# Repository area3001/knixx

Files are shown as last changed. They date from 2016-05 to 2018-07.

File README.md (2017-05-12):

## knixx

Knixx houses all our research and trials into opensource KNX compatible modules.

### knixx SW4

Our first development board is a 4 or 6 button KNX compatible switch which fits in an [Niko](http://niko.eu) (system 45) housing. This form factor is very common in Belgium whilst other parts of Europe use system 55. The board is designed around the ON Semiconductor [NCN5121 KNX Transceiver](http://www.onsemi.com/PowerSolutions/product.do?id=NCN5121) and a STMicroelectronics [STM32F070C6T6 Cortex-M0 Microcontroller](http://www.st.com/content/st_com/en/products/microcontrollers/stm32-32-bit-arm-cortex-mcus/stm32f0-series/stm32f0x0-value-line/stm32f070c6.html). The 4 switch variant provides options to add a Sensirion [SHT20 humidity sensor](https://www.sensirion.com/fileadmin/user_upload/customers/sensirion/Dokumente/Humidity_Sensors/Sensirion_Humidity_Sensors_SHT20_Datasheet_V4.pdf) a Panasonic [EKMC1601113 motion sensor](https://duckduckgo.com/?q=EKMC1601113) and a miniature AMS [TSL2584TSV ambient light sensor](http://ams.com/eng/Products/Light-Sensors/Ambient-Light-Sensors/TSL2584TSV). The board features a Micro USB connector on the back for configuration purposes. 

#### Top 3D render of the 4 switch variant with sensors

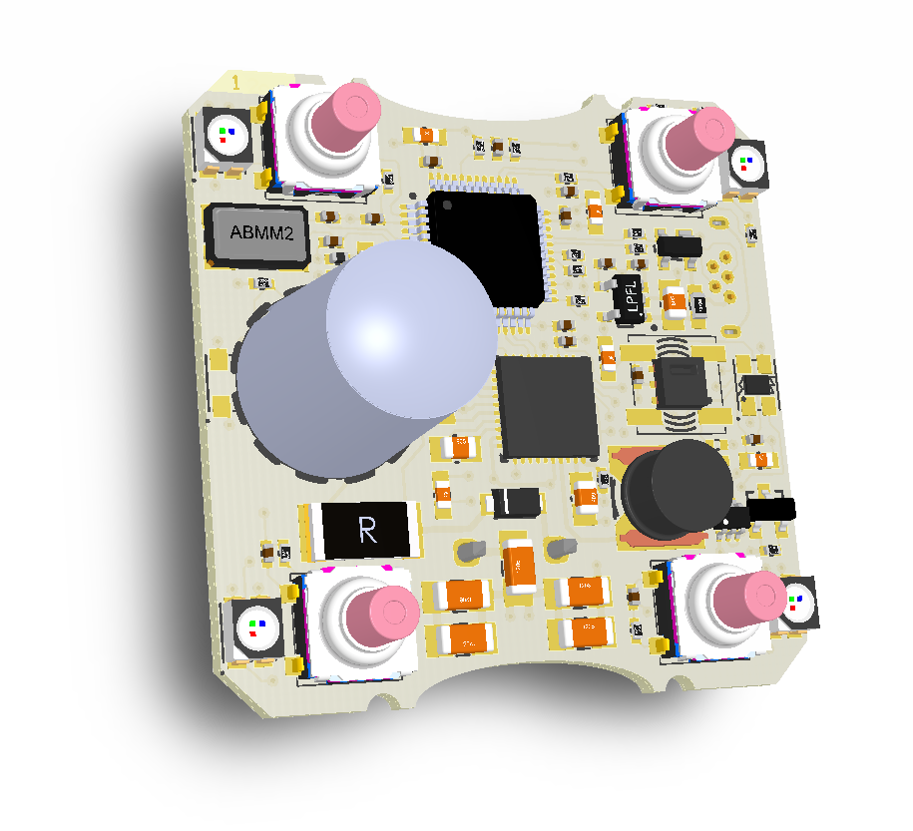
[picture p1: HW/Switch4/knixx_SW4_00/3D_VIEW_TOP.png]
knixx_SW4_00_top 4SW version


#### Top 3D render of the 6 switch variant

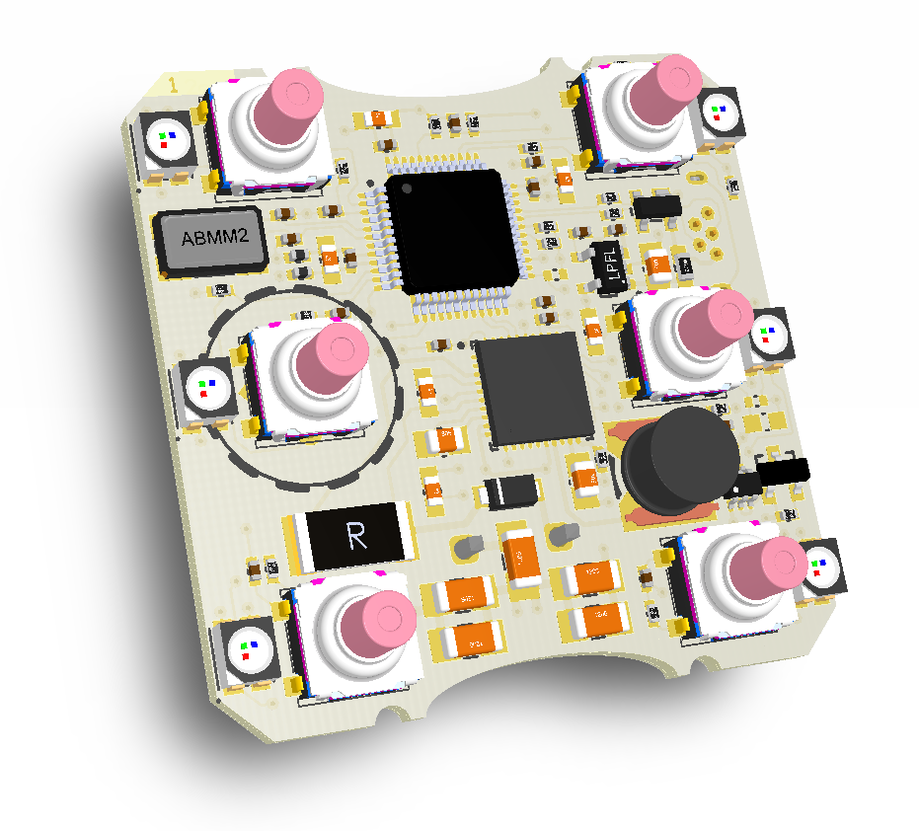
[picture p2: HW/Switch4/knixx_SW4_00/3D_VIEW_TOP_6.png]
knixx_SW4_00_top 6SW version


#### Bottom 3D render

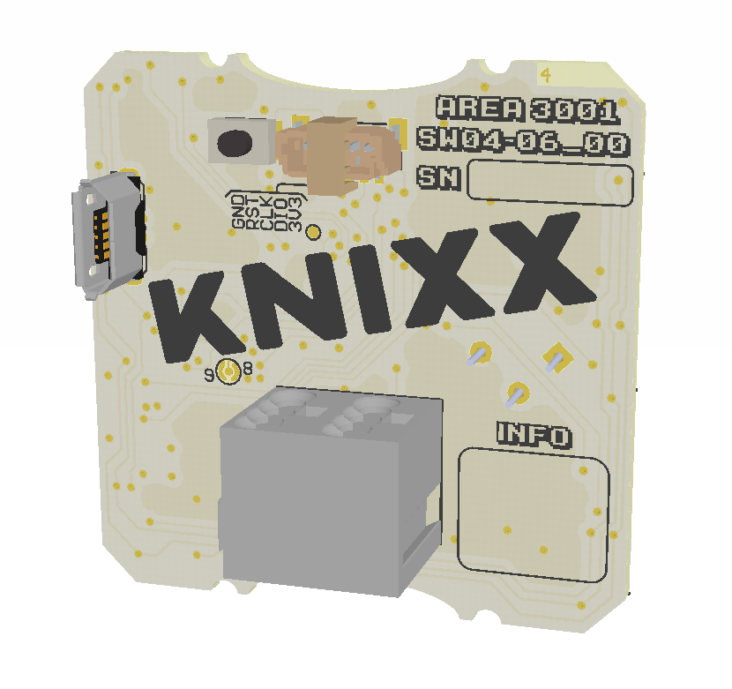
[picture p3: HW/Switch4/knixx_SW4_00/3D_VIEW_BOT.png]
knixx_SW4_00_bot


### knixx Fez

The knixx Fez features the same [NCN5121 KNX Transceiver](http://www.onsemi.com/PowerSolutions/product.do?id=NCN5121) as our switch but interfaces this with the Raspberry Pi. The board als has a [Ti BQ32000](http://www.ti.com/product/BQ32000) RTC, two EEPROMs and a general purpose LED and button.

#### 3D render

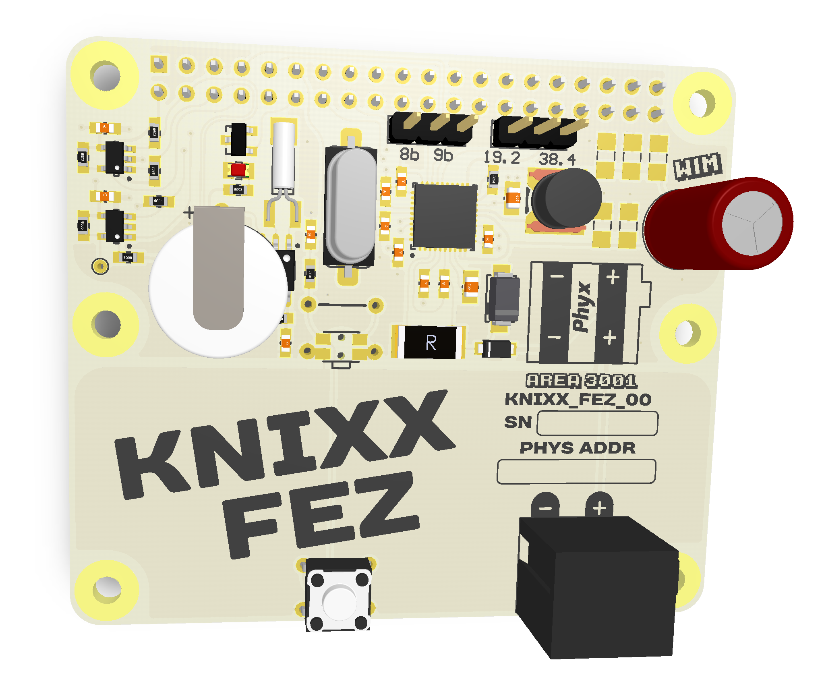
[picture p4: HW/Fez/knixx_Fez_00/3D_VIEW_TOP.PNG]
knixx_Fez_00_top

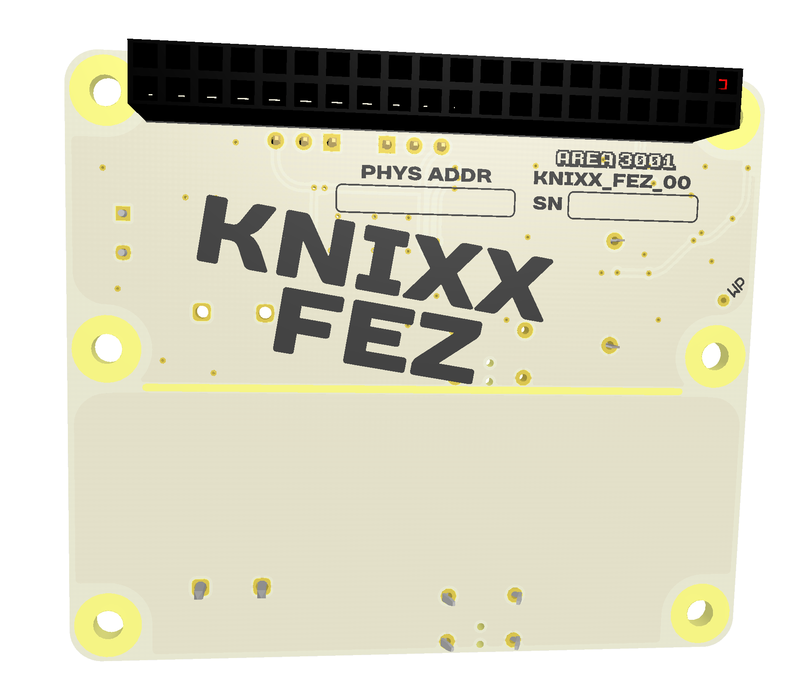
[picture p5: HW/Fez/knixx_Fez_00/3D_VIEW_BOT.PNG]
knixx_Fez_00_bot


### knixx ???

What's next? A system 55 version? Actuators? BeagleBoard Cape?

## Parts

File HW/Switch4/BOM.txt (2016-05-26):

PN; Description; Brand; Supplier1; Supplier1 Price; Supplier1 PN; Supplier2; Supplier2 Price; Supplier2 PN
NCN5121; KNX Transceiver; ON Semi
CLV1A-FKB; RGB PLC4 LED; Cree
TL3301CF260QJ; Tactswitch SMD; E-Switch
KSC621JLFS; Tactswitch SMD 1.6Newton;SMK Components; Farnell; 0,46; 2320054RL; Digikey; 0,387; 401-1748-2-ND
KSC641JLFS; Tactswitch SMD 3Newton; SMK Components; Farnell; ; 2320056RL; Digikey; 0,387; 404-1788-1-ND
11AA010T-I/TT; EEPROM 1Kx8; Microchip; Farnell; 0.148; 157828RL; Digikey; 0,143; 
STM32F030C6T6; uC Cortex-M0, 48 MHz, 32 KB flash, 4 KB RAM, LQFP48; ST Micro
STM32F070C6T6; uC Cortex-M0, 48 MHz, 32 KB flash, 4 KB RAM, LQFP48, USB; ST Micro
243-131; KNX pins; Wago
243-211; KNX connector Red/Black; Wago
SHT20; Digital Humidity Sensor; Sensirion; 
VCNL4010; Fully Integrated Proximity and Ambient Light Sensor with Infrared; Vishay
EKMC1601111; PIR; Panasonic
614105150721; USB conn, Würth or similar straight TH micro USB B connector
Elec. Mic.

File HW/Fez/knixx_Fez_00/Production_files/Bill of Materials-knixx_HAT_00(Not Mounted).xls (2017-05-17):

Bill of Materials |  |  | knixx_HAT
Project: |  | knixx_HAT_00.PrjPcb
Revision: |  | 00
Variant: |  | Not Mounted
Creation Date: | 12/05/2017 | 16:02:06
Print Date: | 2017-05-17 | 11:41:44
Footprint | Comment | LibRef | Designator | Value | Description | Supplier 1 | Supplier Part Number 1 | Quantity
BR-1220_HFN | BR-1220/HFN 35mAh | BAT BR-1220/HFN | BAT1 | 1220 |  | Farnell | 1892653 (https://octopart-clicks.com/click/altium?manufacturer=PANASONIC%20ELECTRONIC%20COMPONENTS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) | 1
C0603_N | CAP_CERAMIC | CAP # 100nF 16V 0603 | C1, C15, C17, C19 | 100nF 16V | Capacitor Ceramic |  |  | 4
C0603_N | CAP_CERAMIC | CAP # 10nF 16V 0603 | C2, C3, C18 | 10nF 16V | Capacitor Ceramic |  |  | 3
C0805_N | CAP_CERAMIC | CAP # 220nF 50V 0805 | C4 | 220nF 50V | Capacitor Ceramic | Farnell | 2496964 (https://octopart-clicks.com/click/altium?sku=2496964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) | 1
C0603_N | CAP_CERAMIC | CAP # 100nF 50V 0603 | C5 | 100nF 50V | Capacitor Ceramic | Farnell | 1759122 (https://octopart-clicks.com/click/altium?sku=1759122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) | 1
C0603_N | CAP_CERAMIC | CAP # 47nF 50V 0603 | C6 | 47nF 50V | Capacitor Ceramic | Farnell | 2496867 (https://octopart-clicks.com/click/altium?sku=2496867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) | 1
C0805_N | CAP_CERAMIC | CAP # 10uF 10V 0805 | C7 | 10uF 10V | Capacitor Ceramic | Farnell | 2320859 (https://octopart-clicks.com/click/altium?sku=2320859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) | 1
C0603_N | CAP_CERAMIC | CAP # 12pF 50V 0402 | C8, C9 | 12pF | Capacitor Ceramic | Farnell | 1759054 (https://octopart-clicks.com/click/altium?sku=1759054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) | 2
C_8x11.5_3.5mm | CAP_POL | CAP 100uF 50V 8x11mm | C16 | 100uF 50V | Capacitor electrolyt | Farnell | 9693793 (https://octopart-clicks.com/click/altium?manufacturer=PANASONIC%20ELECTRONIC%20COMPONENTS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) | 1
WAGO_243-211 | CONNECTOR FOR EIB APPLICATIONS PUSH-WIRE® CONNECTION | Wago 243-211 Connector EIB | CON2 | 243-211 |  | Farnell | 4016014 | 1
ON_SOD-123FL | NTS260SFT1G Schottky Rectifier, Single, 60 V, 2 A, SOD-123, 650 mV | Schottky # NTS260SFT1G | D1 | NTS260SFT1G |  | Farnell | 2473419 (https://octopart-clicks.com/click/altium?sku=2473419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) | 1
LED_0805_RD | Default 0805 Red LED | LED # Red 0805 | D2 |  |  | Farnell | 2099236 (https://octopart-clicks.com/click/altium?sku=2099236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) | 1
SMA_AC | TVS Diode 40V 400W Unidirectional DO-214AC | TVS # UNI 40V 1SMA40AT3G | D3 | 1SMA40AT3G |  | Farnell | 2533119 (https://octopart-clicks.com/click/altium?sku=2533119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) | 1
IND_6045 | 220µH INDUCTOR | IND # 220uH 6.0x6.0mm SRN6045TA-221M | L1 | 220µH IND |  | Farnell | 2616905 (https://octopart-clicks.com/click/altium?sku=2616905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) | 1
HDR1X3 | Header 3 | Pin Header 2.54mm 3way | P3, P4 |  |  |  |  | 2
WAGO_243-131 | SOLDER PIN FOR PCBS UP TO 2 MM | Wago 234-131 Solder pin | P5, P6 | 243-131 |  | Farnell | 2643506 | 2
RCPT2X20 | Header 20X2 | Receptable 2.54mm dual row 40way | Pi |  |  |  |  | 1
R0603_N | RESISTOR | RES # 1K 0603 | R1, R2, R3, R5, R6, R8, R11 | 1K |  |  |  | 7
R2512 | RESISTOR | RES # 27R 2512 | R4 | 27R |  | Farnell | 1265189 | 1
R0603_N | RESISTOR | RES # 1R 0402 | R7 | 1R |  |  |  | 1
R0603_N | RESISTOR | RES # 270R 0603 | R9 | 270R |  | Farnell | 2497841 (https://octopart-clicks.com/click/altium?sku=2497841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) | 1
R0603_N | RESISTOR | RES # 100R 0603 | R10 | 100R |  |  |  | 1
TACTSW | Default TH TACT | SW TACT | SW4 |  |  |  |  | 1
SOT23-3 | 0.2A N-Ch MOSFET Vgs 3.2 | BSS138 N-Ch MOSFET 0.2A 3.2Vgs 60Vds | T1 | BSS138 |  | Farnell | 2432717 (https://octopart-clicks.com/click/altium?sku=2432717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) | 1
TP_1.2mm_0.6mm | TEST_PAD | TP 1.2mm | TP4 | NO BOM |  |  |  | 1
SOT23-5 | Serial EEPROM 64K (8b) SOT35 I2C | EEPROM # I2C 8Kx8b 24LC64T-I/OT | U1, U3 | 24LC64T-I/OT |  | Farnell | 1700992 (https://octopart-clicks.com/click/altium?sku=1700992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) | 2
ONS_QFN40_6x6 | KNX Transceiver for Twisted Pair Networks | KNX # NCN5121 | U2 | NCN5121 |  | DigiKey | NCN5121MNTWGOSTR-ND | 1
SOIC_N_8 | I2C RTC Ti BQ32000 | RTC # BQ32000 | U4 | BQ32000DR |  | Farnell | 1754773 (https://octopart-clicks.com/click/altium?sku=1754773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) | 1
HC49US_SMD | 16MHz 20pF HC49S Fox | XTAL # 16Mhz HC49S | Y1 | 16MHz | Crystal Oscillator | Farnell | 2058001 (https://octopart-clicks.com/click/altium?sku=2058001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) | 1
CMR200T | 32.768Khz CMR200 12.5pF | XTAL # 32.768Khz 12.5pF CMR200 | Y2 | 32.768KHz | Crystal Oscillator | Farnell | 1100758 (https://octopart-clicks.com/click/altium?manufacturer=CITIZEN%20FINETECH%20MIYOTA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) | 1
 |  |  |  |  |  |  |  | 45
Approved |  | Notes

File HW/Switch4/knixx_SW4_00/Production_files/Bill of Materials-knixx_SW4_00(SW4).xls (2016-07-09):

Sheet: BOM Report
Bill of Materials |  |  | Variant [SW4] of [knixx_SW4_00]
Source Data From: |  | knixx_SW4_00.PrjPcb
Project: |  | knixx_SW4_00.PrjPcb
Variant: |  | SW4
Creation Date: | 4/07/2016 | 11:22:56
Print Date: | 42555 | 42555.49438
Footprint | Comment | LibRef | Designator | Value | Description | Supplier 1 | Supplier Part Number 1 | Quantity
C0402 |  | CAP # 100nF 16V 0402 | C1, C6, C7, C13 | 100nF 16V | Capacitor Ceramic | Farnell | 1758896 | 4
C0402 |  | CAP # 10nF 16V 0402 | C2, C8, C9, C10, C11, C12, C20, C21, C23, C25, C28 | 10nF 16V | Capacitor Ceramic | Farnell | 1758924 | 11
C0603_N |  | CAP # 1uF 16V 0603 | C3, C4, C26, C27, C34 | 1uF 16V | Capacitor Ceramic | Farnell | 2320814 | 5
C0805_N |  | CAP # 10uF 10V 0805 | C5, C19 | 10uF 10V | Capacitor Ceramic | Farnell | 2320859 | 2
C0402 |  | CAP # 12pF 50V 0402 | C14, C15 | 12pF | Capacitor Ceramic | Farnell | 2310489 | 2
C0805_N |  | CAP # 220nF 50V 0805 | C16 | 220nF 50V | Capacitor Ceramic | Farnell | 2496964 | 1
C0603_N |  | CAP # 100nF 50V 0603 | C17 | 100nF 50V | Capacitor Ceramic | Farnell | 1759122 | 1
C0603_N |  | CAP # 47nF 50V 0603 | C18 | 47nF 50V | Capacitor Ceramic | Farnell | 2496867 | 1
C1206_N |  | CAP # 22uF 35V 1206 X5R | C29, C30, C31, C32, C33 | 22uF 35V | Capacitor Ceramic | Digikey | 445-8045-1-ND | 5 | China Sourced
WAGO_243-211 | CONNECTOR FOR EIB APPLICATIONS PUSH-WIRE® CONNECTION | Wago 243-211 Connector EIB | CON1 | 243-211 |  |  |  | 1
Cree_CLV1A-FKB | PLCC2 general purpose RGB LED Cree CLV1A-FKB | LED # RGB PLCC2 CLV1A-FKB | D1, D2, D3, D4 | CLV1A-FKB | =Description |  |  | 4
SOT-143 | Low Capacitanse TVS Diode array | TVS # YSSR05 | D7 | YSSR05 | =Description | China |  | 1
ON_SOD-123FL | NTS260SFT1G Schottky Rectifier, Single, 60 V, 2 A, SOD-123, 650 mV | Schottky # NTS260SFT1G | D8 | NTS260SFT1G | =Description | Farnell | 2473419 | 1
L0402 | BLM15AX102SN1D | FER # 1K 0A35 0402 0R49 BLM15AX102SN1D | F1, F2 | 0A35 0R49 |  | Farnell | 2443221 | 2
WE_614105150721 | Vertical Micro USB B 614105150721 | USB Micro B TH VERTICAL 614105150721 | J1 | 614105150721 |  |  |  | 1
IND_6045 | SRU5028-100Y | IND # 10uH 5.2x5.2mm SRU5028-100Y | L1 | 10uH |  | Farnell | 1362078 | 1
WE_665305124022 | Header 1.0mm Shrouded 5 | HDR # SHR 1.0mm 5way - 665305124022 | P1 | 665305124022 |  |  |  | 1
WAGO_243-131 | SOLDER PIN FOR PCBS UP TO 2 MM | Wago 234-131 Solder pin | P2, P3 | 243-131 |  |  |  | 2
SOLDER_SW_C_1MM_3 | 3 pin Solder SW Circular 1mm | SW # Solder 3 pin Circular 1mm | P4 |  |  |  |  | 1
R0402 |  | RES # 100K 0402 | R1, R2 | 100K |  |  |  | 2
R0402 |  | RES # 47R 0402 | R8, R9, R10 | 47R |  |  |  | 3
R0603_N |  | RES # 0R 0603 | R11 | 0R |  |  |  | 1
R0402 |  | RES # 22R 0402 | R12, R13 | 22R |  |  |  | 2
R0402 |  | RES # 10K 0402 | R14, R15, R19, R28 | 10K |  |  |  | 4
R0402 |  | RES # 4K7 0402 | R16, R17 | 4K7 |  |  |  | 2
R2512 |  | RES # 27R 2512 | R20 | 27R |  |  |  | 1
R0402 |  | RES # 1R 0402 | R21 | 1R |  |  |  | 1
R0402 |  | RES # 100R 0402 | R22, R23, R25, R27 | 100R |  |  |  | 4
CK_KSC6xxJ | Sealed Tact Switch for SMT 6,2x6,2x7,7 | SW # TACT KSC621JLFS | SW1, SW2, SW3, SW4 | KSC621JLFS |  | Farnell |  | 4
CK_KMR4 | LP SMD tact sw | SW # KMR4 | SW7 | KMR442GULCLFS |  | Farnell |  | 1
SOT-363 | 0.8A Dual P-Ch MOSGET Vgs -1.2 | NTJD4152PT1G Dual P-Ch MOSFET 0.8A 1.2Vgs 20Vds | T1 | NTJD4152PT1G | =Description | Farnell | 2533191 | 1
SOT23-3 | 0.2A N-Ch MOSFET Vgs 3.2 | BSS138 N-Ch MOSFET 0.2A 3.2Vgs 60Vds | T2 | BSS138 |  | Farnell | 2432717 | 1
TP_0.8mm |  | TP # 0.8mm | TP1 | NO BOM |  |  |  | 1
STM_LQFP48_N | Entry-level ARM Cortex-M0 Value line MCU with up to 32 Kbytes Flash, 48 MHz CPU, USB | M0 # STM32F070C6T6 | U1 | STM32F070C6T6 | =Description | Farnell | 2488283 | 1
PAN_EKMC1601111 | PIR 5m White | PIR 5m WH EKMC1601111 | U2 | EKMC1601111 | =Description | Farnell | 2095728 | 1
SNS_DFN6 | Sensirion SHT20 temperature and humidity sensor I2C | TMP HUM # SHT20 | U3 | SHT20 | =Description | Digikey | 1649-1004-1-ND | 1
TI_DBV_R-PDSO-G5 | 3V3 100mA Ultra Low Noise LDO | LDO # 3V3 0A1 ULN TPS79133 | U4 | TPS79133 | =Description | Farnell | 8461767 | 1
ONS_QFN40_6x6 | KNX Transceiver for Twisted Pair Networks | KNX # NCN5121 | U7 | NCN5121 | =Description |  |  | 1
AMS_6TSV | TSL2584TSV Light-to-Digital Device | LGHT # TSL2584TSV | U8 | TSL2584TSV | =Description | Digikey | TSL2584TSVTR-ND | 1
ABMM2 | 16MHZ ABMM2 | XTAL # 16Mhz ABMM2 | Y1 | 16MHz | Crystal Oscillator 4pin casing | Farnell | 2101343 | 1
 |  |  |  |  |  |  |  | 82
Approved |  | Notes

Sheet: Project Information
Project Full Path | C:\Users\WimVG\Dropbox\Electronics\knixx_SW4_00\knixx_SW4_00.PrjPcb
Project Filename | knixx_SW4_00.PrjPcb
Variant Name | SW4
Data-Source Filename | knixx_SW4_00.PrjPcb
Data-Source Full Path | C:\Users\WimVG\Dropbox\Electronics\knixx_SW4_00\knixx_SW4_00.PrjPcb
Title | Bill of Materials For Variant [SW4] of Project [knixx_SW4_00.PrjPcb] (PCB Document : knixx_SW4_00.PcbDoc)
Total Quantity | 82
Report Time | 11:22:56
Report Date | 4/07/2016
Report Date & Tine | 4/07/2016 11:22:56
Output Name | Bill of Materials
Output Type | BOM_PartType
Output Generator Name | BOM
Output Generator Description | Bill of Materials

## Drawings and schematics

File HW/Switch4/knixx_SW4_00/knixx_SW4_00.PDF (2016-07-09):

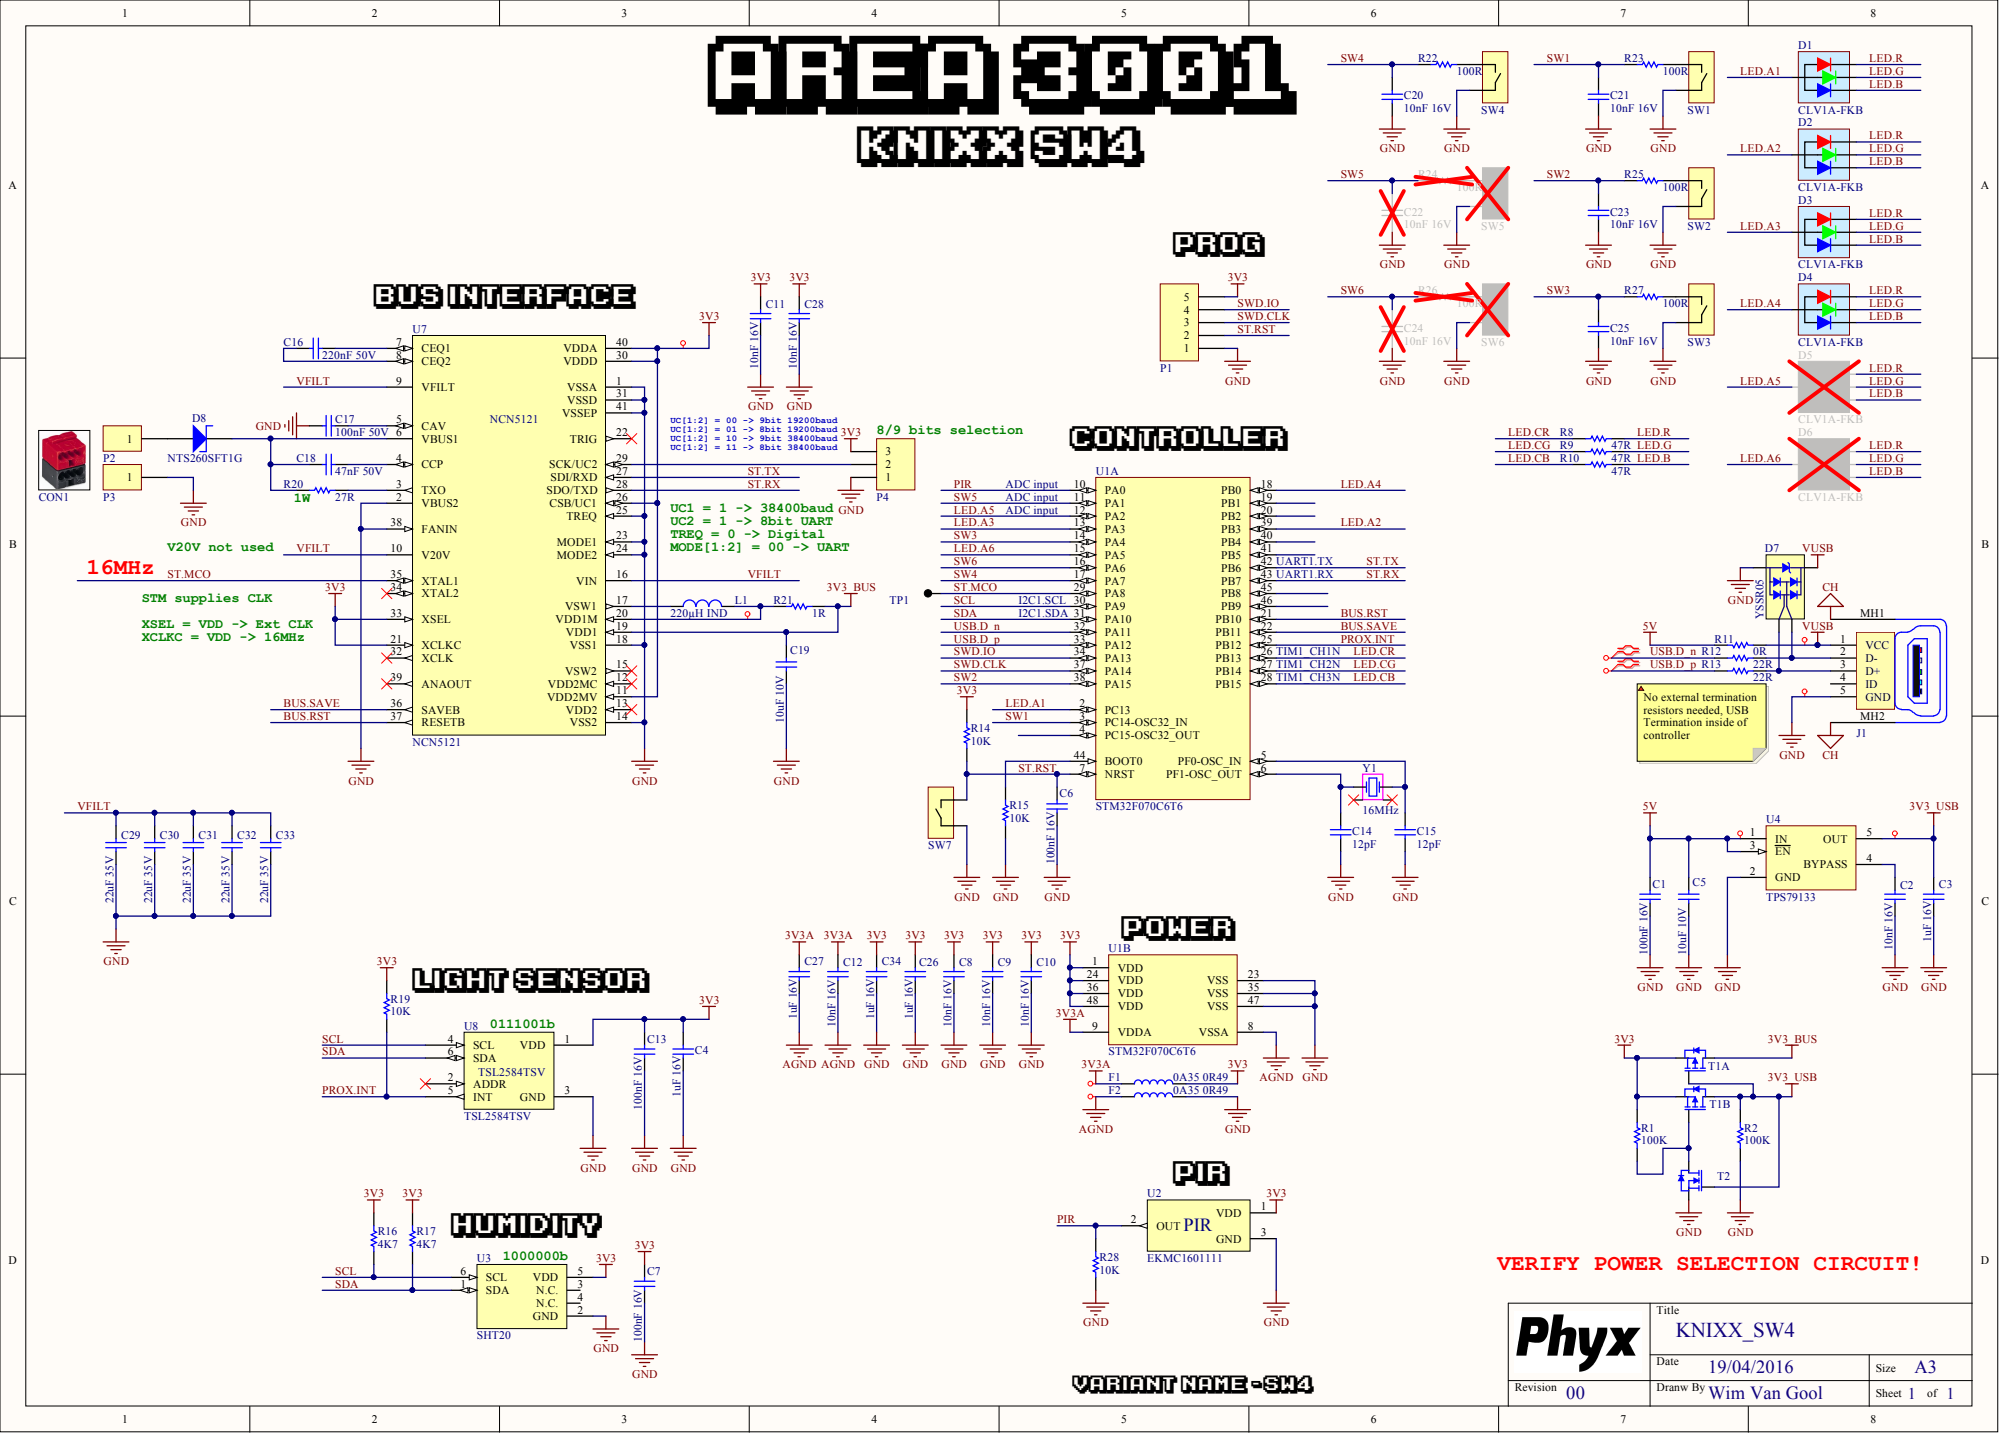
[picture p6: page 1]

XSEL = VDD -> Ext CLK
XCLKC = VDD -> 16MHz

VERIFY POWER SELECTION CIRCUIT!

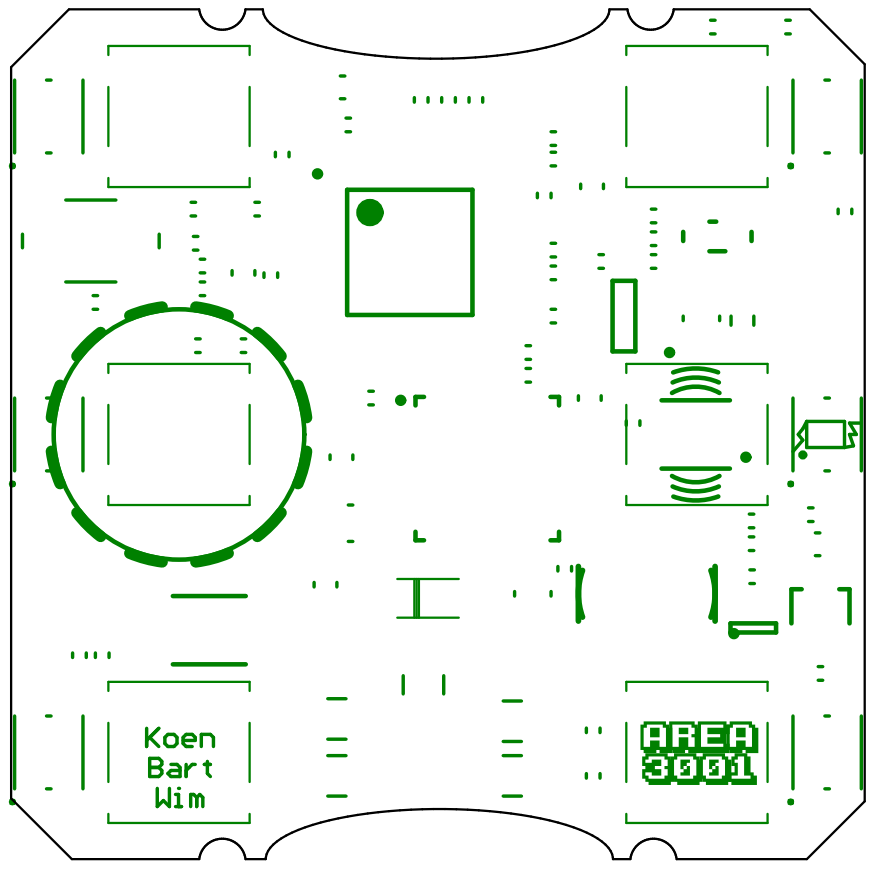
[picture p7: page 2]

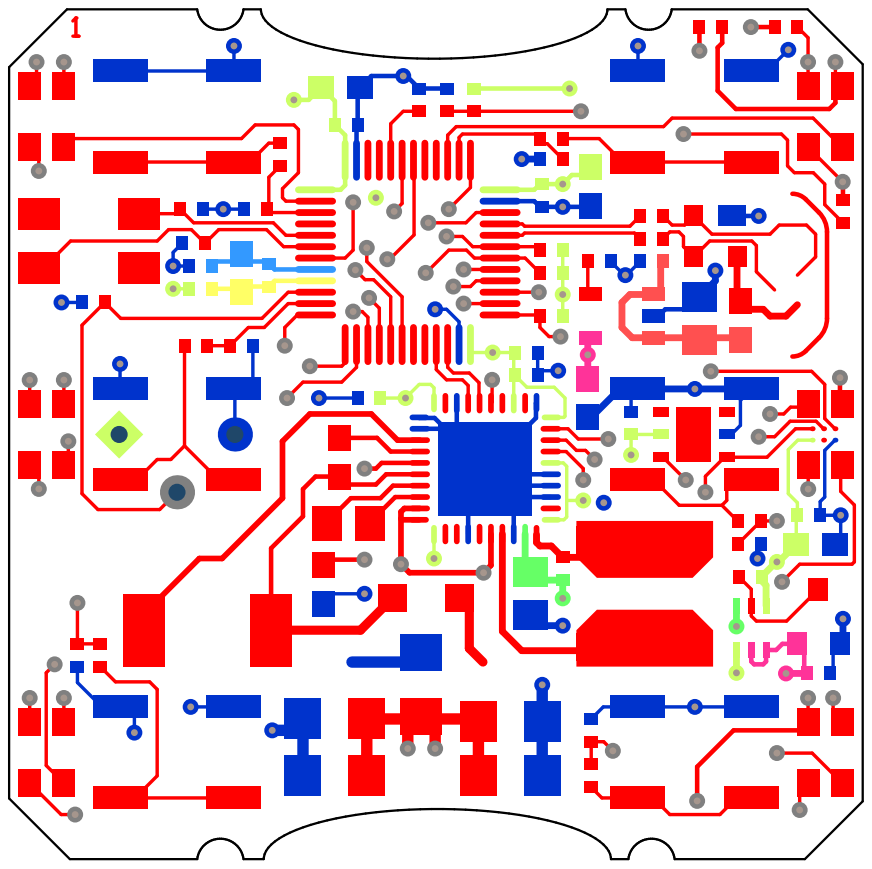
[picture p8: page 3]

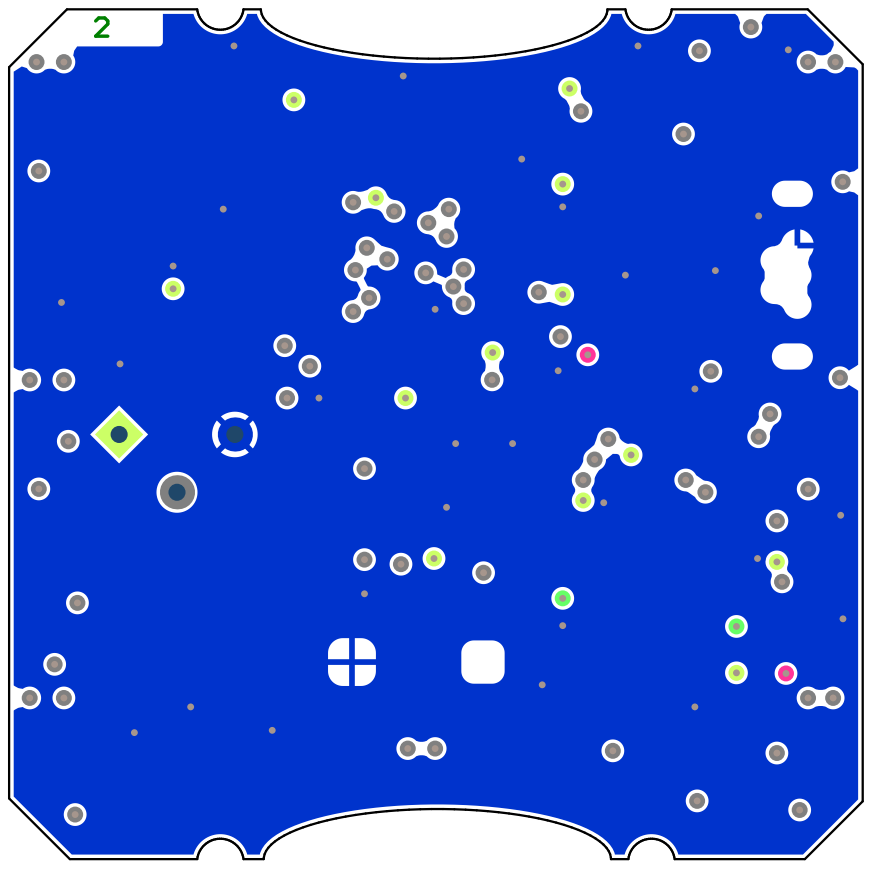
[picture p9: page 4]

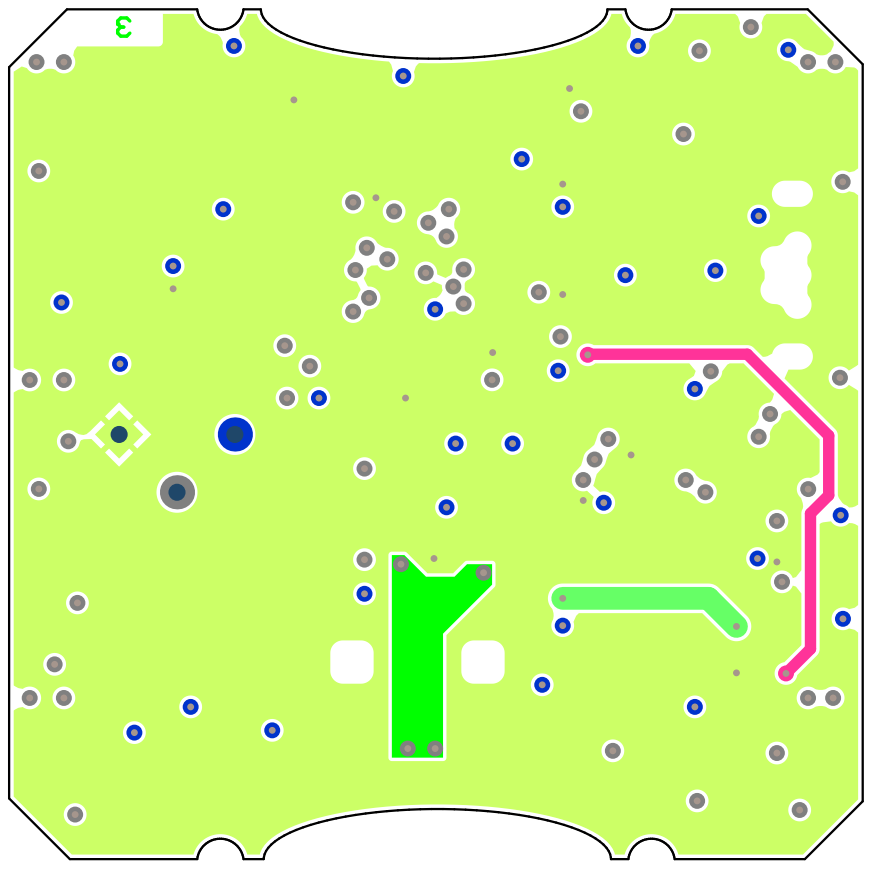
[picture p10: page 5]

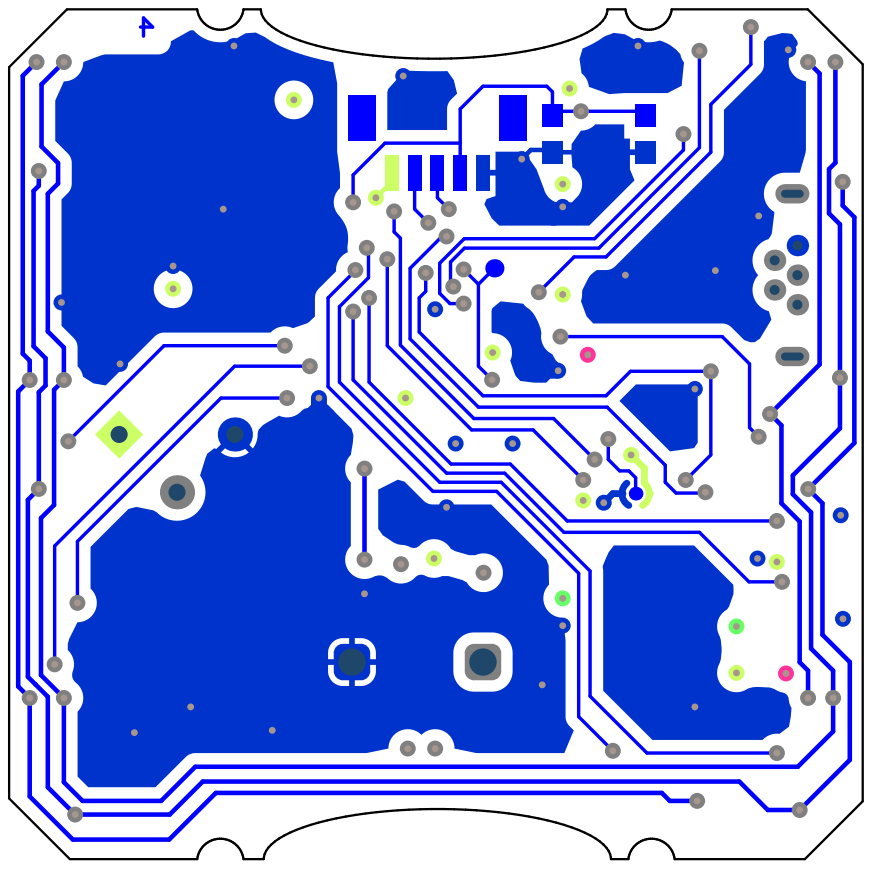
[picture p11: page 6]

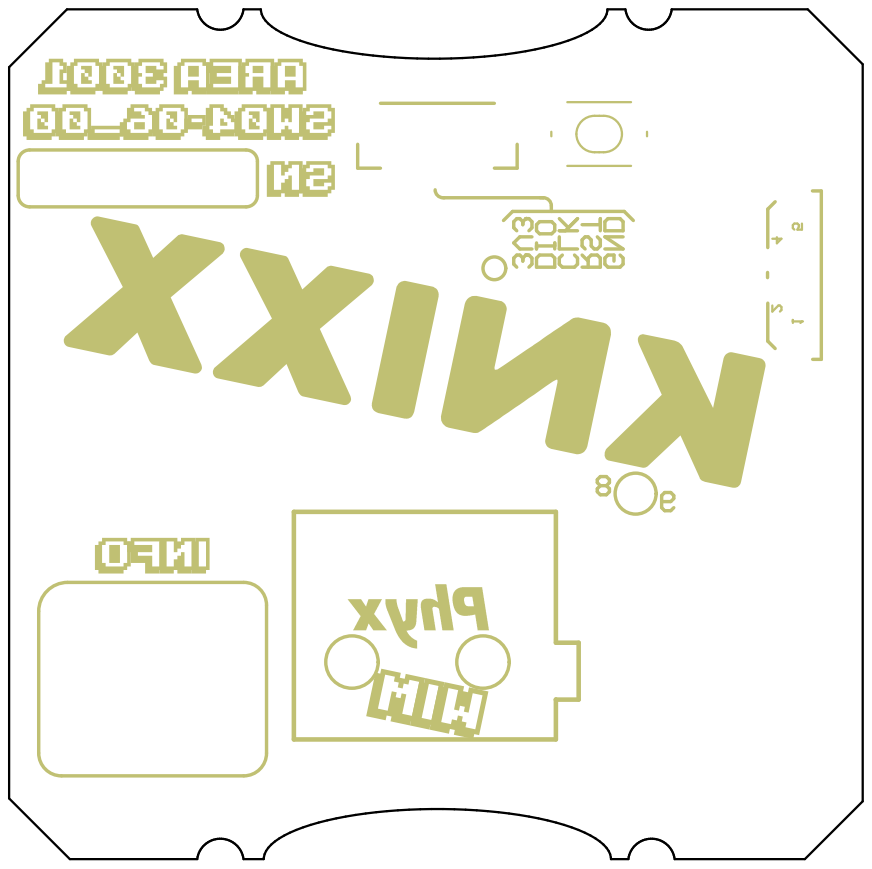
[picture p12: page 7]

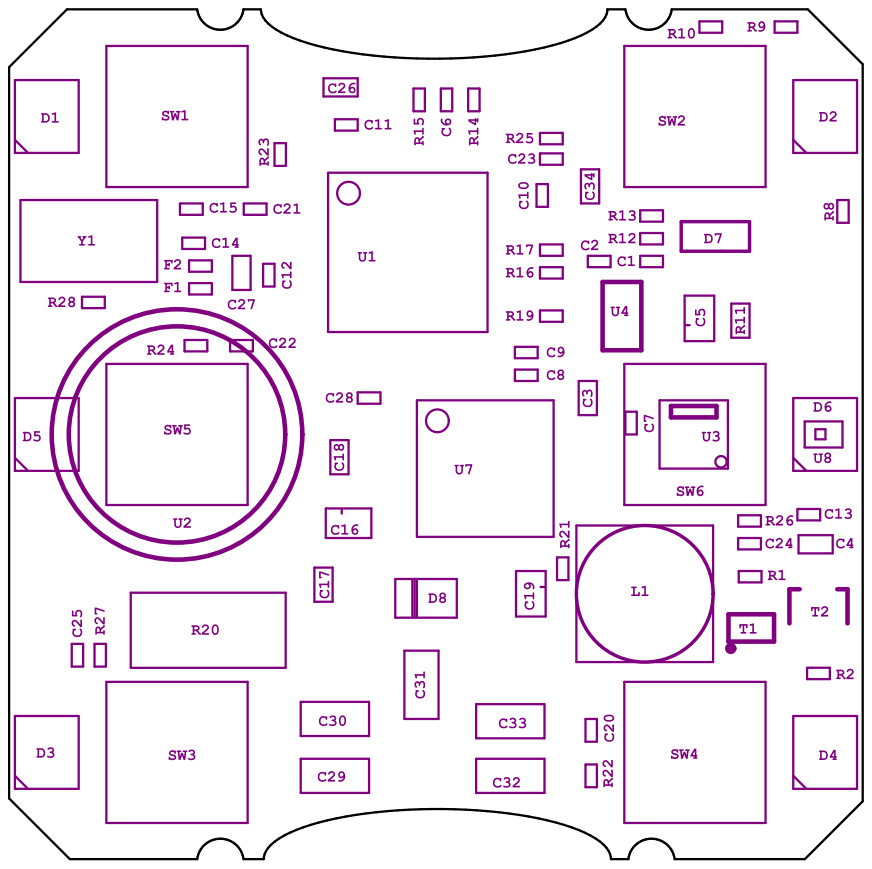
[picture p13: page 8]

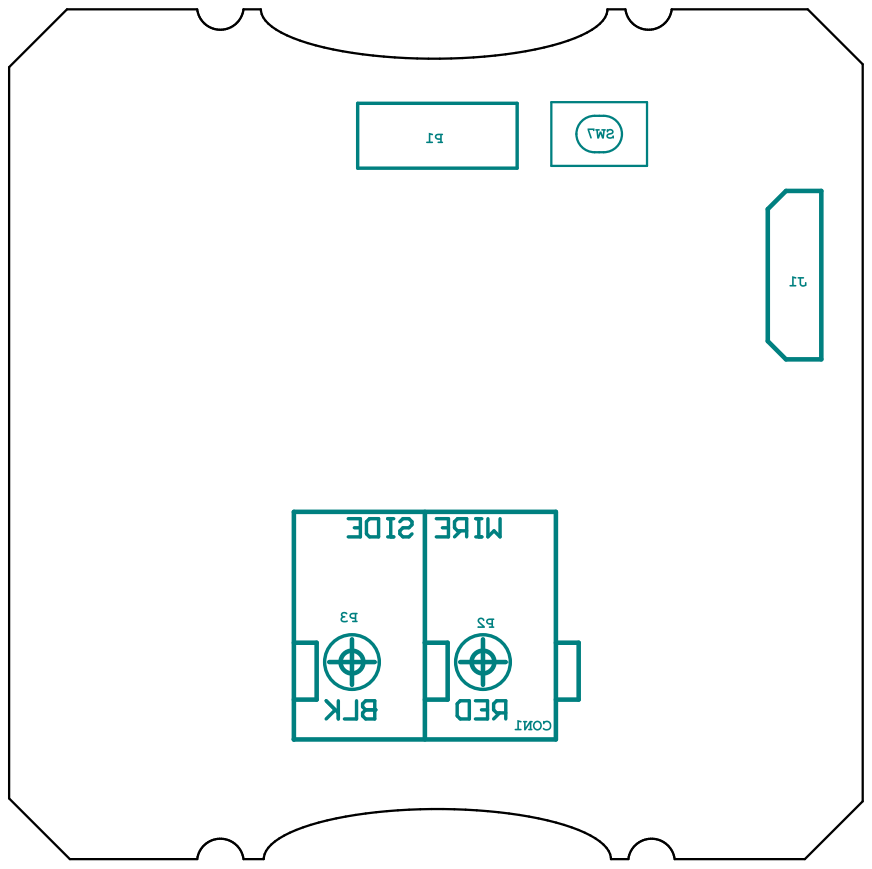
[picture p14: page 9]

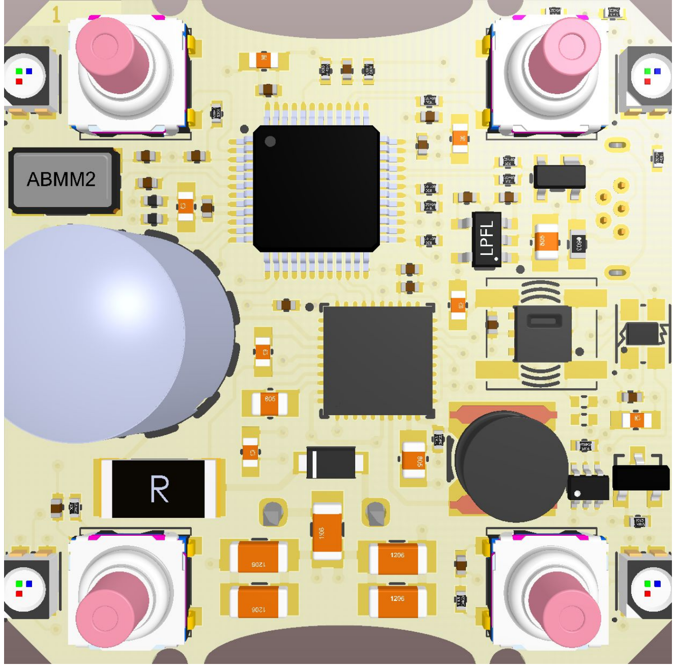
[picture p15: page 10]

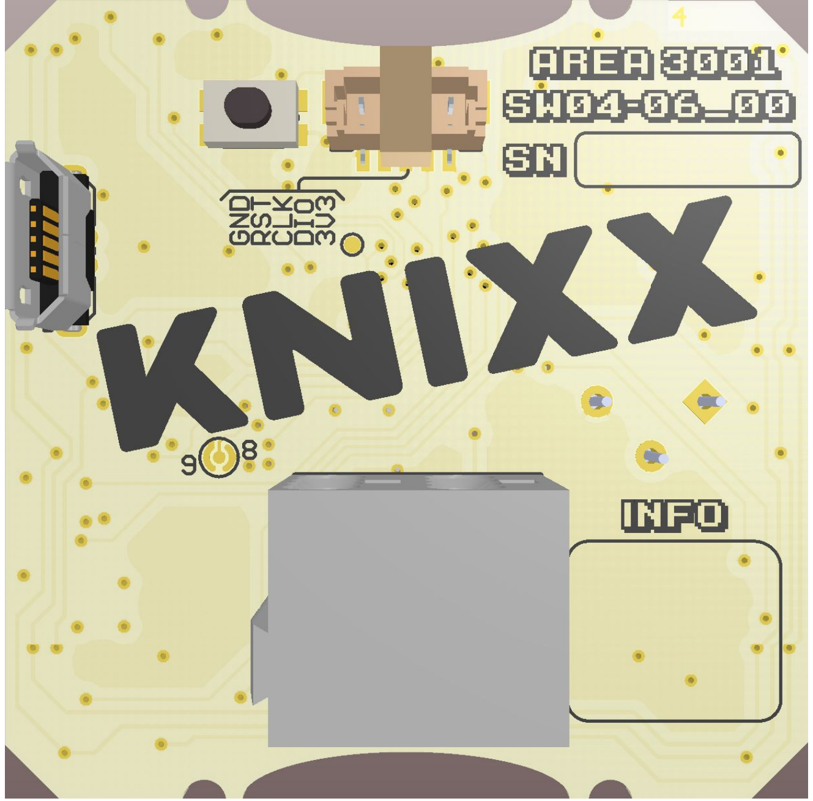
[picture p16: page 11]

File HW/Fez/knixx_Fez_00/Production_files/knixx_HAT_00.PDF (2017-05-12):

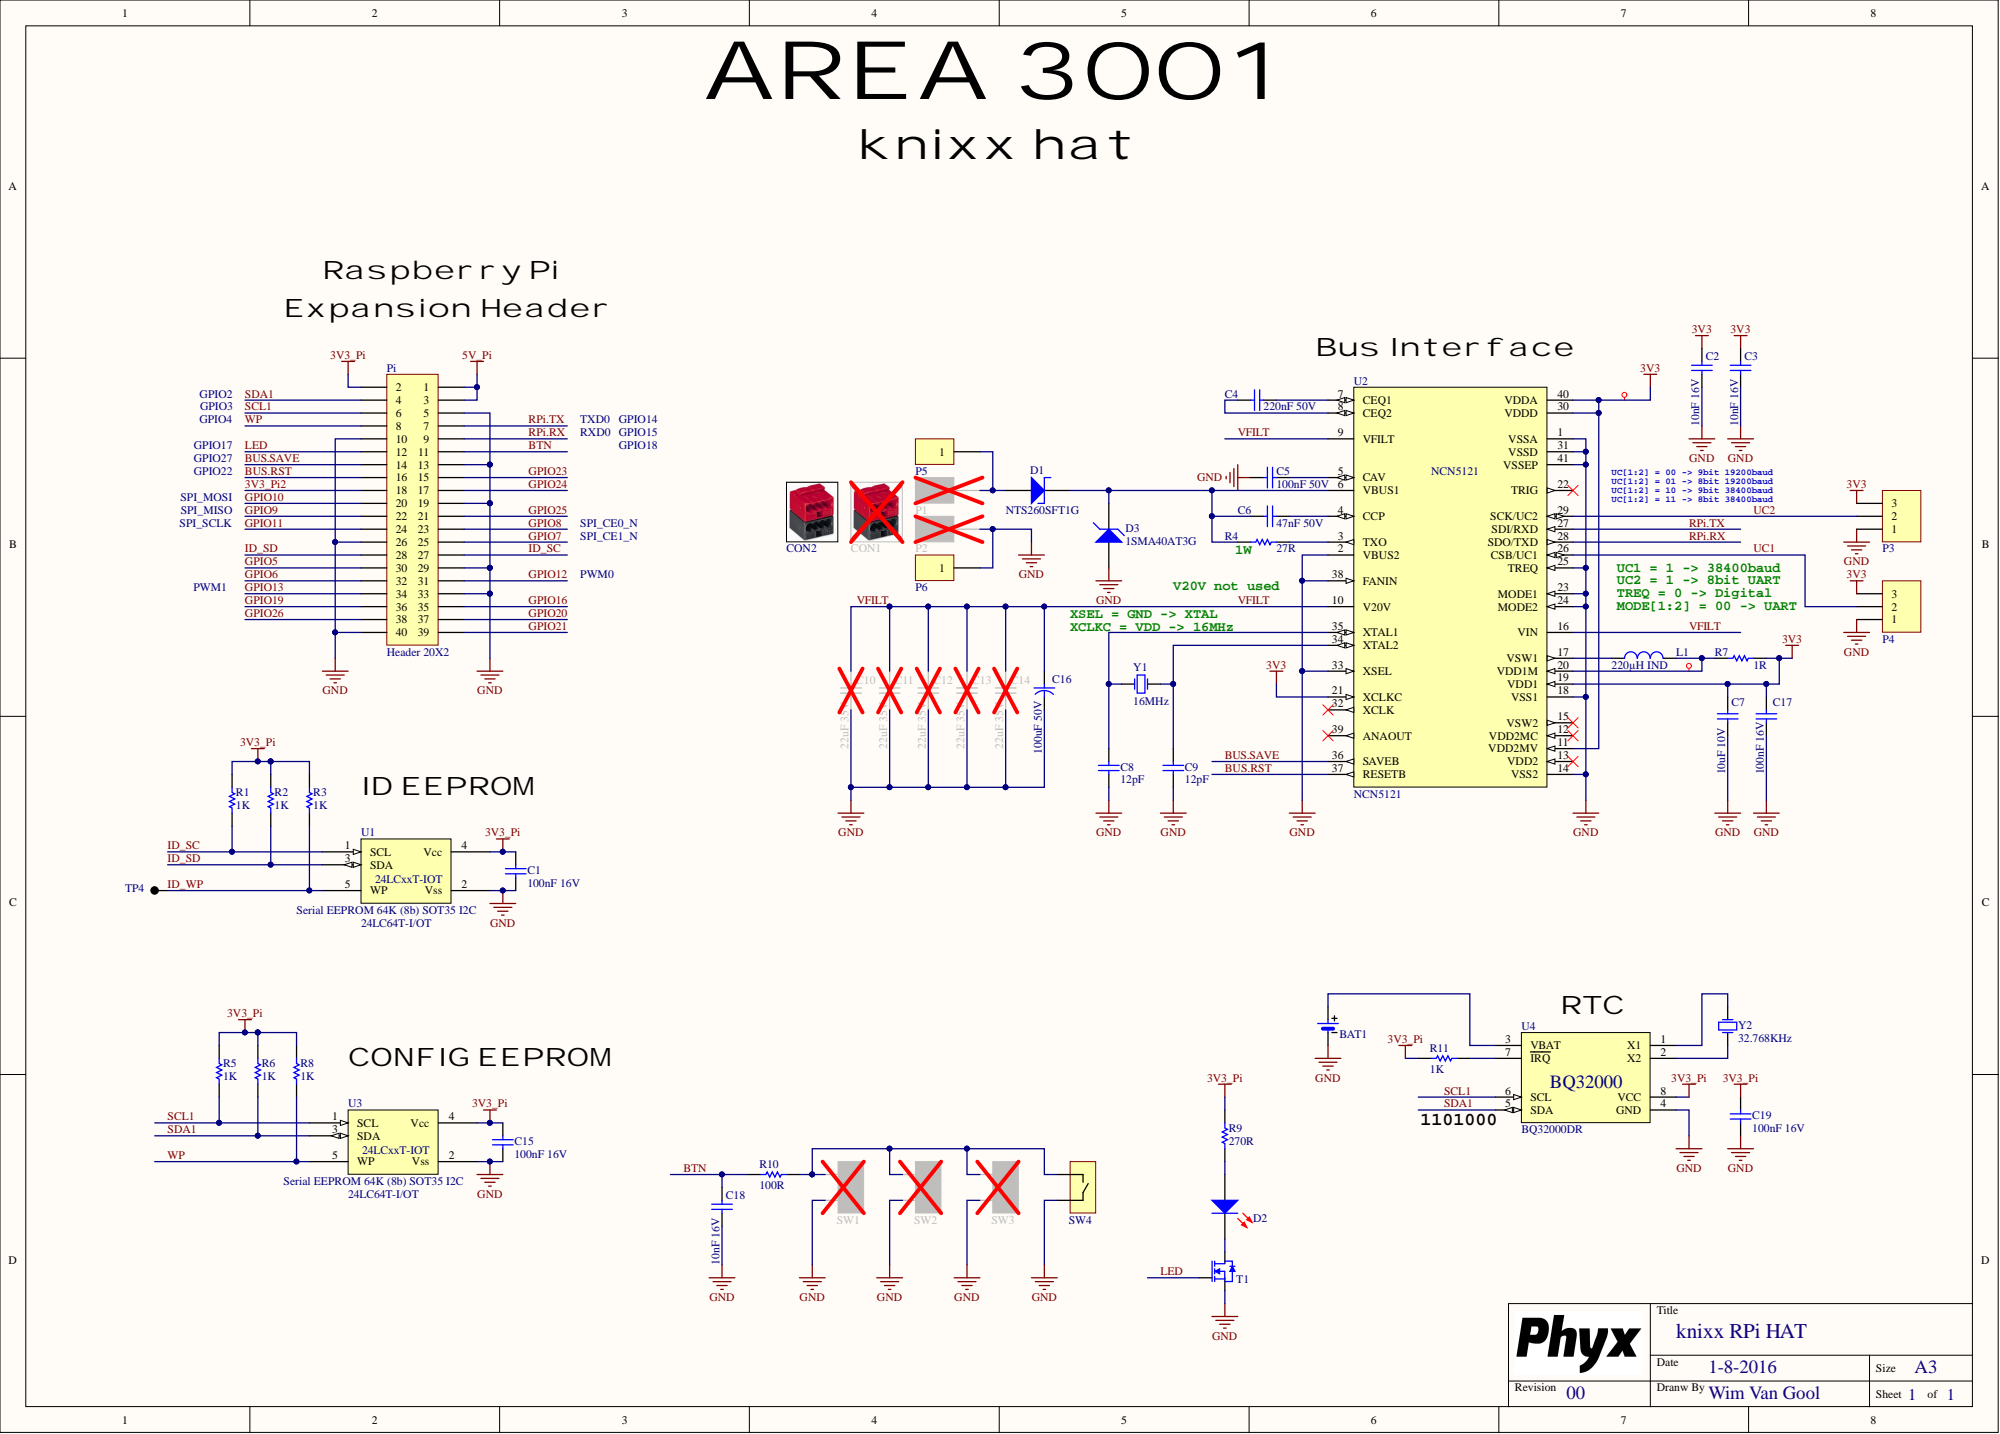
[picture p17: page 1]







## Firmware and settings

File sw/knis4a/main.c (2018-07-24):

/*
 * The MIT License (MIT)
 *
 * Copyright (c) 2018 Bart Van Der Meerssche <bart@flukso.net>
 *
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
 * THE SOFTWARE IS PROVIDED "AS IS", WITHOUT WARRANTY OF ANY KIND, EXPRESS OR
 * IMPLIED, INCLUDING BUT NOT LIMITED TO THE WARRANTIES OF MERCHANTABILITY,
 * FITNESS FOR A PARTICULAR PURPOSE AND NONINFRINGEMENT. IN NO EVENT SHALL THE
 * AUTHORS OR COPYRIGHT HOLDERS BE LIABLE FOR ANY CLAIM, DAMAGES OR OTHER
 * LIABILITY, WHETHER IN AN ACTION OF CONTRACT, TORT OR OTHERWISE, ARISING FROM,
 * OUT OF OR IN CONNECTION WITH THE SOFTWARE OR THE USE OR OTHER DEALINGS IN THE
 * SOFTWARE.
 */

#include <libopencmsis/core_cm3.h>
#include <libopencm3/cm3/nvic.h>
#include <libopencm3/cm3/systick.h>
#include <libopencm3/stm32/rcc.h>
#include <libopencm3/stm32/flash.h>
#include <libopencm3/stm32/gpio.h>
#include "clock.h"
#include "usb.h"
#include "cli.h"
#include "button.h"
#include "ncn.h"
#include "config.h"
#include "pwm.h"
#include "led.h"

static void rcc_wait_for_osc_not_ready(enum rcc_osc osc)
{
	while (rcc_is_osc_ready(osc));
}

static void rcc_set_pll_source(enum rcc_osc osc)
{
	switch (osc) {
	case RCC_HSI:
		RCC_CFGR &= ~RCC_CFGR_PLLSRC;
		break;
	case RCC_HSE:
		RCC_CFGR |= RCC_CFGR_PLLSRC;;
		break;
	case RCC_LSE:
	case RCC_HSI48:
	case RCC_HSI14:
	case RCC_LSI:
	case RCC_PLL:
		/* Do nothing */
		break;
	}
}

static void clk_tree_setup(void)
{
	/* cf. rcc_clock_setup_in_hsi_out_48mhz */
	rcc_osc_on(RCC_HSI);
	rcc_wait_for_osc_ready(RCC_HSI);
	rcc_set_sysclk_source(RCC_HSI);
	rcc_osc_on(RCC_HSE);
	rcc_wait_for_osc_ready(RCC_HSE);
	rcc_osc_off(RCC_PLL);
	rcc_wait_for_osc_not_ready(RCC_PLL);
	flash_set_ws(FLASH_ACR_LATENCY_024_048MHZ);
#ifdef NUCLEO
	rcc_set_pll_multiplication_factor(RCC_CFGR_PLLMUL_MUL6);
#else
	/* 16MHz * 3 = 48MHz */
	rcc_set_pll_multiplication_factor(RCC_CFGR_PLLMUL_MUL3);
#endif
	rcc_set_pll_source(RCC_HSE);
	rcc_osc_on(RCC_PLL);
	rcc_wait_for_osc_ready(RCC_PLL);
	rcc_set_sysclk_source(RCC_PLL);
	rcc_set_hpre(RCC_CFGR_HPRE_NODIV);
	rcc_set_ppre(RCC_CFGR_PPRE_NODIV);
	rcc_apb1_frequency = 48000000UL;
	rcc_ahb_frequency = 48000000UL;
	rcc_set_usbclk_source(RCC_PLL);
}

static void mco_setup(void)
{
	rcc_periph_clock_enable(RCC_GPIOA);
	gpio_mode_setup(GPIOA, GPIO_MODE_AF, GPIO_PUPD_NONE, GPIO8);
	gpio_set_output_options(GPIOA, GPIO_OTYPE_PP, GPIO_OSPEED_100MHZ, GPIO8);
	gpio_set_af(GPIOA, GPIO_AF0, GPIO8);
	rcc_set_mco(RCC_CFGR_MCO_HSE);
}

int main(void)
{
	cm_disable_interrupts();
	clk_tree_setup();
	mco_setup();
	clock_setup();
	usb_setup();
	cli_setup();
	pwm_init();
	led_setup();
	button_setup();
	ncn_setup();
	cm_enable_interrupts();

	while (1) {
		__WFI();
	}

	return 0;
}

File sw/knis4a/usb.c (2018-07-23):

/*
 * The MIT License (MIT)
 *
 * Copyright (c) 2018 Bart Van Der Meerssche <bart@flukso.net>
 *
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
 * THE SOFTWARE IS PROVIDED "AS IS", WITHOUT WARRANTY OF ANY KIND, EXPRESS OR
 * IMPLIED, INCLUDING BUT NOT LIMITED TO THE WARRANTIES OF MERCHANTABILITY,
 * FITNESS FOR A PARTICULAR PURPOSE AND NONINFRINGEMENT. IN NO EVENT SHALL THE
 * AUTHORS OR COPYRIGHT HOLDERS BE LIABLE FOR ANY CLAIM, DAMAGES OR OTHER
 * LIABILITY, WHETHER IN AN ACTION OF CONTRACT, TORT OR OTHERWISE, ARISING FROM,
 * OUT OF OR IN CONNECTION WITH THE SOFTWARE OR THE USE OR OTHER DEALINGS IN THE
 * SOFTWARE.
 */

#include <stdlib.h>
#include <string.h>
#include <libopencm3/cm3/nvic.h>
#include <libopencm3/stm32/rcc.h>
#include <libopencm3/usb/usbd.h>
#include <libopencm3/usb/cdc.h>
#include <libopencm3/usb/dfu.h>
#include "usb.h"
#include "cli.h"

static usbd_device *dev;
static bool usb_connected = false;

static const struct usb_device_descriptor descr = {
	.bLength = USB_DT_DEVICE_SIZE,
	.bDescriptorType = USB_DT_DEVICE,
	.bcdUSB = 0x0200,
	.bDeviceClass = 0xef,   /* miscellaneous device */
	.bDeviceSubClass = 2,   /* common class */
	.bDeviceProtocol = 1,   /* interface association */
	.bMaxPacketSize0 = 64,
	.idVendor = 0x1209,
	.idProduct = 0xa7ea,
	.bcdDevice = 0x0100,
	.iManufacturer = 1,
	.iProduct = 2,
	.iSerialNumber = 3,
	.bNumConfigurations = 1,
};

/*
 * This notification endpoint isn't implemented. According to CDC spec its
 * optional, but its absence causes a NULL pointer dereference in Linux
 * cdc_acm driver.
 */
static const struct usb_endpoint_descriptor console_comm_endp[] = {{
	.bLength = USB_DT_ENDPOINT_SIZE,
	.bDescriptorType = USB_DT_ENDPOINT,
	.bEndpointAddress = EP_COMM(USB_ITF_CONSOLE),
	.bmAttributes = USB_ENDPOINT_ATTR_INTERRUPT,
	.wMaxPacketSize = USB_INT_MAX_PACKET_SIZE,
	.bInterval = 128,
}};

static const struct usb_endpoint_descriptor console_data_endp[] = {{
	.bLength = USB_DT_ENDPOINT_SIZE,
	.bDescriptorType = USB_DT_ENDPOINT,
	.bEndpointAddress = EP_DATA_OUT(USB_ITF_CONSOLE),
	.bmAttributes = USB_ENDPOINT_ATTR_BULK,
	.wMaxPacketSize = USB_BULK_MAX_PACKET_SIZE,
	.bInterval = 0,
}, {
	.bLength = USB_DT_ENDPOINT_SIZE,
	.bDescriptorType = USB_DT_ENDPOINT,
	.bEndpointAddress = EP_DATA_IN(USB_ITF_CONSOLE),
	.bmAttributes = USB_ENDPOINT_ATTR_BULK,
	.wMaxPacketSize = USB_BULK_MAX_PACKET_SIZE,
	.bInterval = 0,
}};

static const struct {
	struct usb_cdc_header_descriptor header;
	struct usb_cdc_call_management_descriptor call_mgmt;
	struct usb_cdc_acm_descriptor acm;
	struct usb_cdc_union_descriptor cdc_union;
} __attribute__((packed)) console_cdcacm_functional_descriptors = {
	.header = {
		.bFunctionLength = sizeof(struct usb_cdc_header_descriptor),
		.bDescriptorType = CS_INTERFACE,
		.bDescriptorSubtype = USB_CDC_TYPE_HEADER,
		.bcdCDC = 0x0110,
	},
	.call_mgmt = {
		.bFunctionLength =
			sizeof(struct usb_cdc_call_management_descriptor),
		.bDescriptorType = CS_INTERFACE,
		.bDescriptorSubtype = USB_CDC_TYPE_CALL_MANAGEMENT,
		.bmCapabilities = 0,
		.bDataInterface = 1,
	},
	.acm = {
		.bFunctionLength = sizeof(struct usb_cdc_acm_descriptor),
		.bDescriptorType = CS_INTERFACE,
		.bDescriptorSubtype = USB_CDC_TYPE_ACM,
		.bmCapabilities = 0,
	},
	.cdc_union = {
		.bFunctionLength = sizeof(struct usb_cdc_union_descriptor),
		.bDescriptorType = CS_INTERFACE,
		.bDescriptorSubtype = USB_CDC_TYPE_UNION,
		.bControlInterface = 0,
		.bSubordinateInterface0 = 1,
	},
};

static const struct usb_interface_descriptor console_comm_iface[] = {{
	.bLength = USB_DT_INTERFACE_SIZE,
	.bDescriptorType = USB_DT_INTERFACE,
	.bInterfaceNumber = 0,
	.bAlternateSetting = 0,
	.bNumEndpoints = 1,
	.bInterfaceClass = USB_CLASS_CDC,
	.bInterfaceSubClass = USB_CDC_SUBCLASS_ACM,
	.bInterfaceProtocol = USB_CDC_PROTOCOL_AT,
	.iInterface = 4,

	.endpoint = console_comm_endp,
	.extra = &console_cdcacm_functional_descriptors,
	.extralen = sizeof(console_cdcacm_functional_descriptors),
}};

static const struct usb_interface_descriptor console_data_iface[] = {{
	.bLength = USB_DT_INTERFACE_SIZE,
	.bDescriptorType = USB_DT_INTERFACE,
	.bInterfaceNumber = 1,
	.bAlternateSetting = 0,
	.bNumEndpoints = 2,
	.bInterfaceClass = USB_CLASS_DATA,
	.bInterfaceSubClass = 0,
	.bInterfaceProtocol = 0,
	.iInterface = 0,

	.endpoint = console_data_endp,
}};

static const struct usb_iface_assoc_descriptor console_assoc = {
	.bLength = USB_DT_INTERFACE_ASSOCIATION_SIZE,
	.bDescriptorType = USB_DT_INTERFACE_ASSOCIATION,
	.bFirstInterface = 0,
	.bInterfaceCount = 2,
	.bFunctionClass = USB_CLASS_CDC,
	.bFunctionSubClass = USB_CDC_SUBCLASS_ACM,
	.bFunctionProtocol = USB_CDC_PROTOCOL_AT,
	.iFunction = 0,
};

static const struct usb_endpoint_descriptor log_comm_endp[] = {{
	.bLength = USB_DT_ENDPOINT_SIZE,
	.bDescriptorType = USB_DT_ENDPOINT,
	.bEndpointAddress = EP_COMM(USB_ITF_LOG),
	.bmAttributes = USB_ENDPOINT_ATTR_INTERRUPT,
	.wMaxPacketSize = USB_INT_MAX_PACKET_SIZE,
	.bInterval = 128,
}};

static const struct usb_endpoint_descriptor log_data_endp[] = {{
	.bLength = USB_DT_ENDPOINT_SIZE,
	.bDescriptorType = USB_DT_ENDPOINT,
	.bEndpointAddress = EP_DATA_OUT(USB_ITF_LOG),
	.bmAttributes = USB_ENDPOINT_ATTR_BULK,
	.wMaxPacketSize = USB_BULK_MAX_PACKET_SIZE,
	.bInterval = 0,
}, {
	.bLength = USB_DT_ENDPOINT_SIZE,
	.bDescriptorType = USB_DT_ENDPOINT,
	.bEndpointAddress = EP_DATA_IN(USB_ITF_LOG),
	.bmAttributes = USB_ENDPOINT_ATTR_BULK,
	.wMaxPacketSize = USB_BULK_MAX_PACKET_SIZE,
	.bInterval = 0,
}};

static const struct {
	struct usb_cdc_header_descriptor header;
	struct usb_cdc_call_management_descriptor call_mgmt;
	struct usb_cdc_acm_descriptor acm;
	struct usb_cdc_union_descriptor cdc_union;
} __attribute__((packed)) log_cdcacm_functional_descriptors = {
	.header = {
		.bFunctionLength = sizeof(struct usb_cdc_header_descriptor),
		.bDescriptorType = CS_INTERFACE,
		.bDescriptorSubtype = USB_CDC_TYPE_HEADER,
		.bcdCDC = 0x0110,
	},
	.call_mgmt = {
		.bFunctionLength =
			sizeof(struct usb_cdc_call_management_descriptor),
		.bDescriptorType = CS_INTERFACE,
		.bDescriptorSubtype = USB_CDC_TYPE_CALL_MANAGEMENT,
		.bmCapabilities = 0,
		.bDataInterface = 3,
	},
	.acm = {
		.bFunctionLength = sizeof(struct usb_cdc_acm_descriptor),
		.bDescriptorType = CS_INTERFACE,
		.bDescriptorSubtype = USB_CDC_TYPE_ACM,
		.bmCapabilities = 0,
	},
	.cdc_union = {
		.bFunctionLength = sizeof(struct usb_cdc_union_descriptor),
		.bDescriptorType = CS_INTERFACE,
		.bDescriptorSubtype = USB_CDC_TYPE_UNION,
		.bControlInterface = 2,
		.bSubordinateInterface0 = 3,
	},
};
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

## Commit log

2016-05-26 USB controller + connector added
2016-07-09 Design files added
    Added the design and production files for the knixx_SW4.
    [Bill of Materials-knixx_SW4_00(SW4).xls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]
2016-08-03 SW start
    [Bill of Materials-knixx_SW4_00(SW4).xls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]
2016-08-19 removed Panasonic link
    On request from Panasonic Industrial, we removed the direct link to the EKMC1601113 PIR sensor. (The link has been replaced with a direct from DuckDuckGo)
2016-10-23 [usb] enumerate a cdc-acm device implementing a loopback on the bulk ep's
2016-10-24 [cli] attach a basic console to the cdc-acm itf
2016-11-09 [clock] switch to 16MHz xtal
2016-12-26 [usb] usb handler is now interrupt-driven
2016-12-26 [usb] allow printing to console/debug/tpuart
2016-12-26 [button] initialize and log to debug
2016-12-26 [log] create printf-alike logging function
2016-12-28 [ncn] allow tx/rx over uart
2016-12-29 [LED] first attempt to output a PWM signal for RGB
2017-01-11 [LED] WIP: second try not working
    [led.c, main.c, pwm.c]
2017-01-18 [LED] refactoring setting leds
2017-05-12 knixx Fez 00 added
    Design and production files for the knixx Fez board added
    [Bill of Materials-knixx_HAT_00(Not Mounted).xls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]
2017-05-17 BoM updated
    added ordercodes, replaced coil with the correct one in the BoM
    [Bill of Materials-knixx_HAT_00(Not Mounted).xls]
2018-07-22 [make] add NUCLEO compilation switch
2018-07-22 [mini-printf] swap out stdio for mini-printf
    [button.c]
2018-07-22 [button] button 5 & 6 were deleted from rev2 pcb6
2018-07-23 [ld] update linker script to work with STM32F072C8T6
2018-07-23 [usb] keep track of usb connection state
2018-07-24 [log] add msec resolution timestamping to log traces
